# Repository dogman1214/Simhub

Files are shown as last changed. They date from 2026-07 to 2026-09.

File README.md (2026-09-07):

# Simhub
A custom-designed macropad design for my sim-racing use, and for general purpose as well.
This isn't physical at the moment, but rather a design you use to build your own macropad!

# Features:
* 3D - printed custom case
* 3 x 4 switch arrangement
* EC11 rotary encoder, with a switch built in
* USB-C connectivity
# CAD Model:

Everything is secured in place with 4 M3 screws and bolts, with the bolts serving a dual purpose as the base legs. The case is to be 3d-printed, along with the knob for the rotary encoder.

CAD
The render was made in Blender
The model was made in FreeCAD.

# PCB
This is the PCB, it was designed in KiCad.

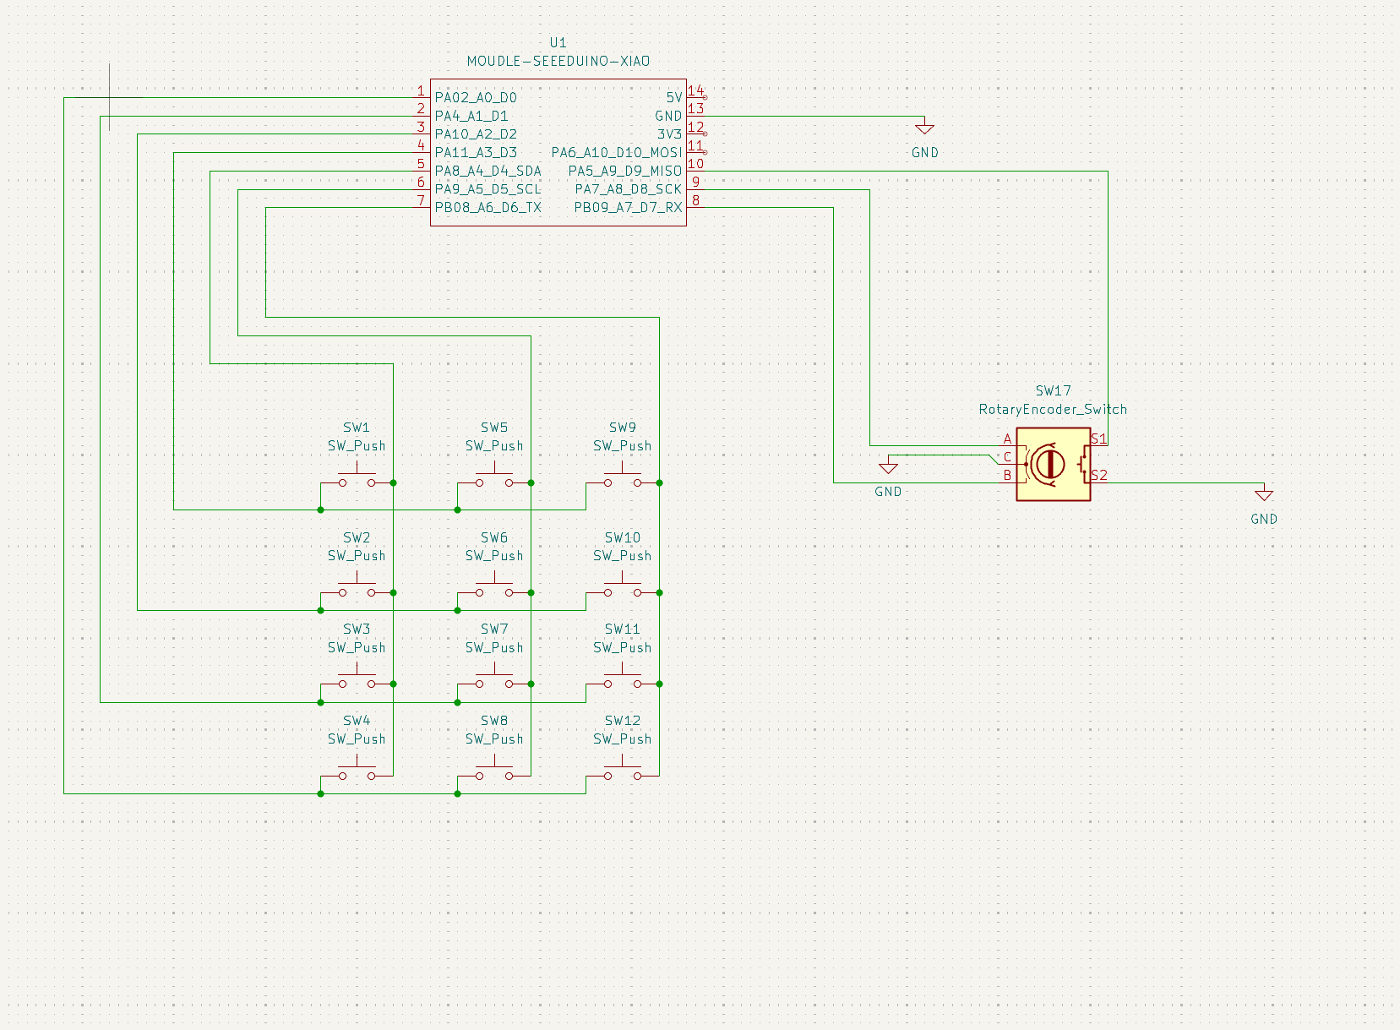
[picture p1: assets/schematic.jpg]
Schematic
Schematic 

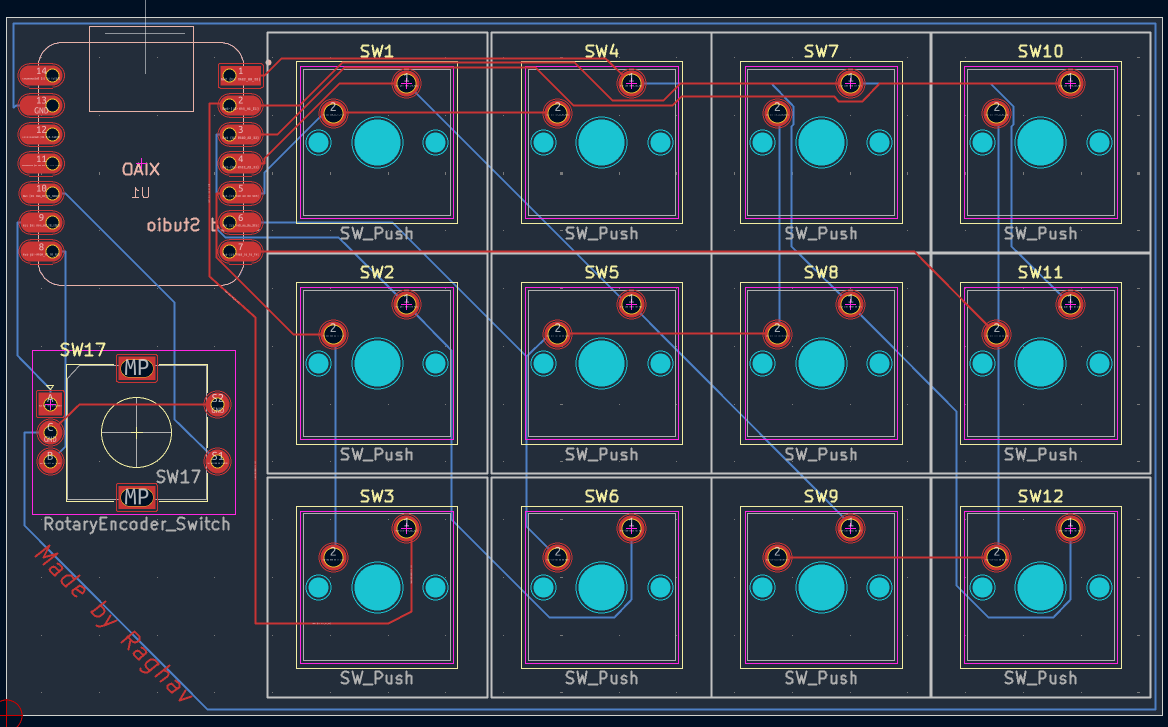
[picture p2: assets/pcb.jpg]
PCB
PCB 

# Firmware
This hackpad uses QMK firmware for everything.
Since it was designed with video-game assistance in mind, you have to map all the keys in-game to use them.

*This keyboard has two modes.*

To swap between custom in-game keyboard usage and a normal numpad style keyboard, click down on the rotary encoder.

#Be aware: This Bill of Materials is what is expected to be bought & used. I haven't built the macropad yet.

### BOM:
This is eveyrthing you need to make this macropad:
* 12x Cherry MX Switches
* 12x DSA Keycaps
* 4x M3x16mm nuts and bolts
* 1x EC11 Rotary Encoder
* 1x XIAO RP2040
* 1x Case (3 printed parts)

# Bill of Materials - what you'll realistically buy

| Item Number | Description | Quantity | Unit Price (USD) | Extended Price (USD) | Vendor | Link |
|---|---|---|---|---|---|---|
| 4809-EC11E15204A3-ND | EC11E15204A3 Alps Alpine ENCODER INCREM QUAD VERT PC PIN | 1 | 4.41 | 4.41 | Digi-Key | https://www.digikey.com/en/products/detail/alps-alpine/EC11E15204A3/21721644 |
| 1597-102010428-ND | 102010428 Seeed Technology Co., Ltd XIAO RP2040 | 1 | 4.88 | 4.88 | Digi-Key | https://www.digikey.com/en/products/detail/seeed-technology-co-ltd/102010428/14672129 |
| CHERRY MX2A RGB Brown Kit| 36 mechanical keyboard switches (tactile, no click) | 1 | 19.99 | 19.99 | Amazon | https://www.amazon.com/dp/B0FYR9Z777 |
| Fgruh 750PCS M3 Screws | M3 hex socket bolts/nuts/washers set | 1 | 9.99 | 9.99 | Amazon | https://www.amazon.com/dp/B0FGV5FCBN |
| NeWear Relegendable Caps | DSA-style customizable transparent keycaps (12 pack) | 1 | 12.50 | 12.50 | Amazon | https://www.amazon.com/dp/B0DH91XV4T |
| Simhubb-PCBfiles_Y2 | PCB prototype Y2-13145810A, Green, 1.6mm, HASL (with lead) | 5 | 0.40 | 2.00 | JLCPCB | (Generated from your Gerber ZIP; no product link) |
| Body.stl | 3D print PETG FDM, Standard finish, Translucent | 1 | 5.40 | 5.40 | Hudson Creative Group | (Custom print; no link) |
| Cover.stl | 3D print PETG FDM, Standard finish, Translucent | 1 | 5.40 | 5.40 | Hudson Creative Group | (Custom print; no link) |
| Knob.stl | 3D print PETG FDM, Standard finish, Translucent | 1 | 5.40 | 5.40 | Hudson Creative Group | (Custom print; no link) |
 |

I hope you like this project/macropad!

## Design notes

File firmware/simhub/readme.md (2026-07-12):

# Simhub
A custom 12-key handwired macropad with a rotary encoder powered by a Seeed XIAO RP2040
* Keyboard Maintainer: Raghav Sharma
* Hardware Supported: Seeed XIAO RP2040, MX style switches, EC11 rotary encoder, custom pcb.
* Hardware Availability: https://hackpad.hackclub.com/

Make example for this keyboard, after setting up the build environment:
```
make Simhub:default
```

Flashing example for this keyboard:
```
make Simhub:default:flash
```

See the [build environment setup](https://docs.qmk.fm/#/getting_started_build_tools) and the [make instructions](https://docs.qmk.fm/#/getting_started_make_guide) for more information.

# Bootloader
Enter the bootloader in 3 ways:
* Bootmagic reset: Hold down the top left key (the key at (0,0) and plug in the keyboard.
* Physical reset button: press the RESET button on the XIAO board while holding the BOOT button.
* Keycode in layout: Press the key mapped to QK_BOOT if it is available.

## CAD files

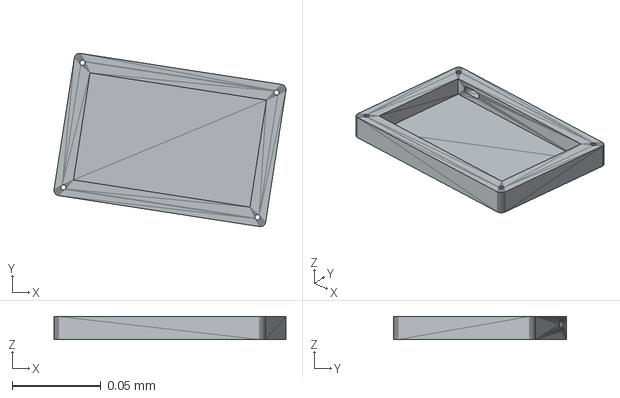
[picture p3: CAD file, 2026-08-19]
production/Body.step
0.13 x 0.0974 x 0.013 mm

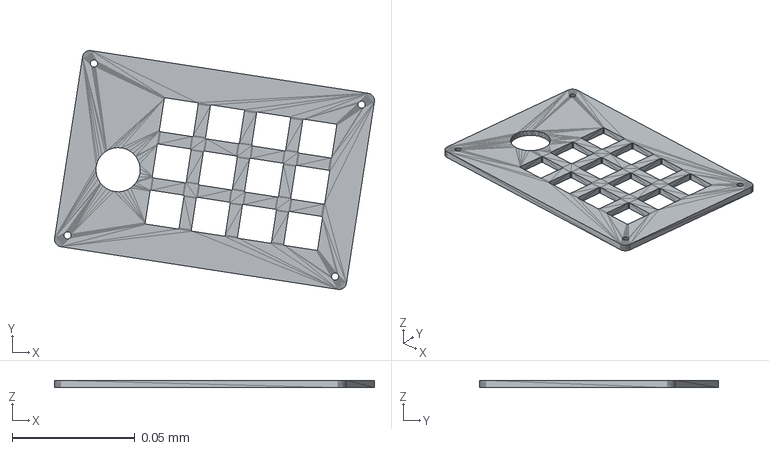
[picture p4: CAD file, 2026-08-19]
production/Cover.step
0.13 x 0.0974 x 0.003 mm

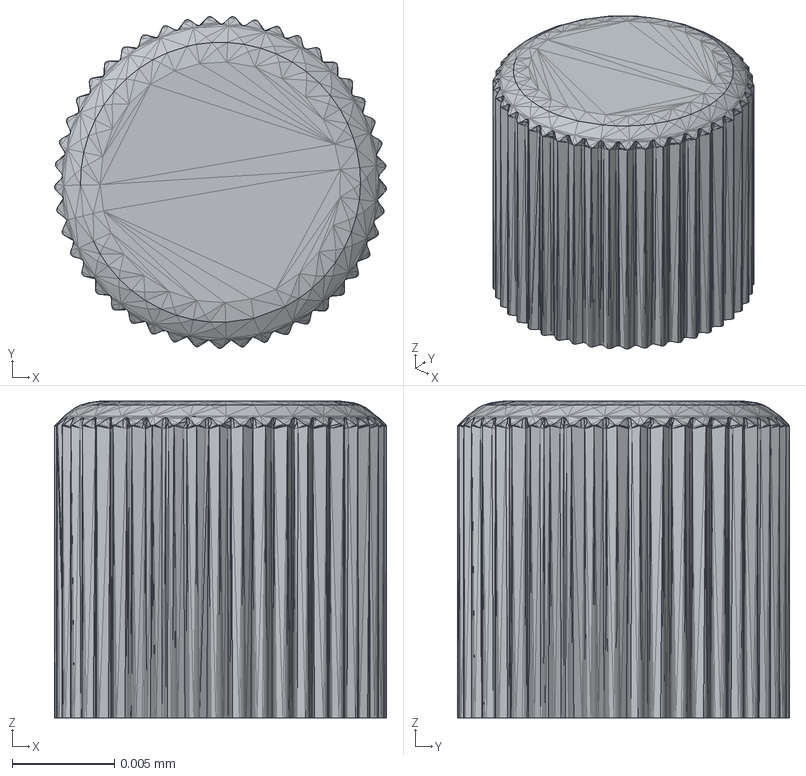
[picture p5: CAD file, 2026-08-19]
production/Knob.step
0.0163 x 0.0162 x 0.0155 mm

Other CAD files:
production/Body.stl
production/Cover.stl
production/Knob.stl

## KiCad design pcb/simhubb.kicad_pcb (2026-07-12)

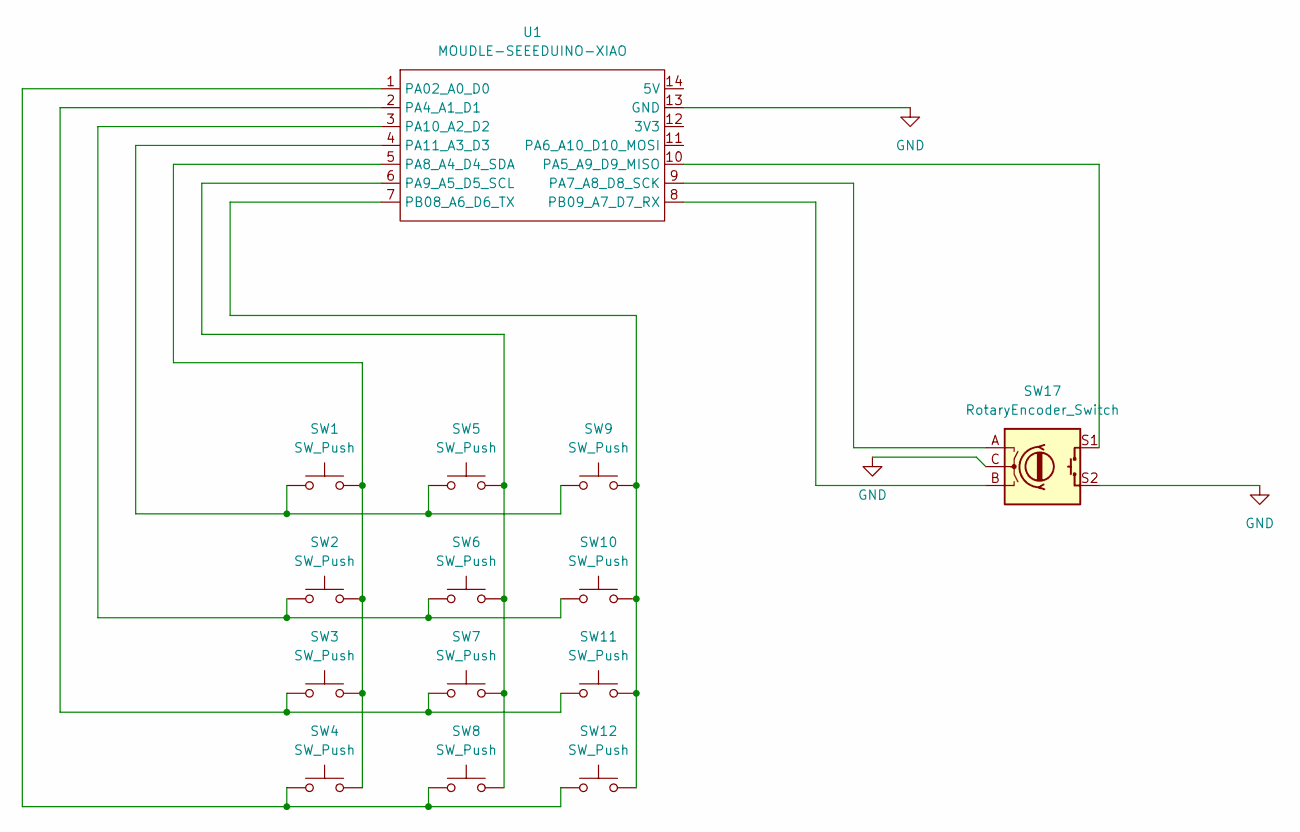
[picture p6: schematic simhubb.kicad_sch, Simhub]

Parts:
SW1, SW2, SW3, SW4, SW5, SW6, SW7, SW8, SW9, SW10, SW11, SW12: SW_Push; SW_Cherry_MX_1.00u_PCB
SW17: RotaryEncoder_Switch; RotaryEncoder_Alps_EC11E-Switch_Vertical_H20mm
U1: MOUDLE-SEEEDUINO-XIAO; XIAO-Generic-Hybrid-14P-2.54-21X17.8MM

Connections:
GND: SW17.C, SW17.S2, U1.13 (GND)
unnamed: SW4.1, SW8.1, SW12.1, U1.1 (PA02_A0_D0)
unnamed: SW3.1, SW7.1, SW11.1, U1.2 (PA4_A1_D1)
unnamed: SW17.S1, U1.10 (PA5_A9_D9_MISO)
unnamed: SW17.A, U1.9 (PA7_A8_D8_SCK)
unnamed: SW1.2, SW2.2, SW3.2, SW4.2, U1.5 (PA8_A4_D4_SDA)
unnamed: SW5.2, SW6.2, SW7.2, SW8.2, U1.6 (PA9_A5_D5_SCL)
unnamed: SW2.1, SW6.1, SW10.1, U1.3 (PA10_A2_D2)
unnamed: SW1.1, SW5.1, SW9.1, U1.4 (PA11_A3_D3)
unnamed: SW9.2, SW10.2, SW11.2, SW12.2, U1.7 (PB08_A6_D6_TX)
unnamed: SW17.B, U1.8 (PB09_A7_D7_RX)

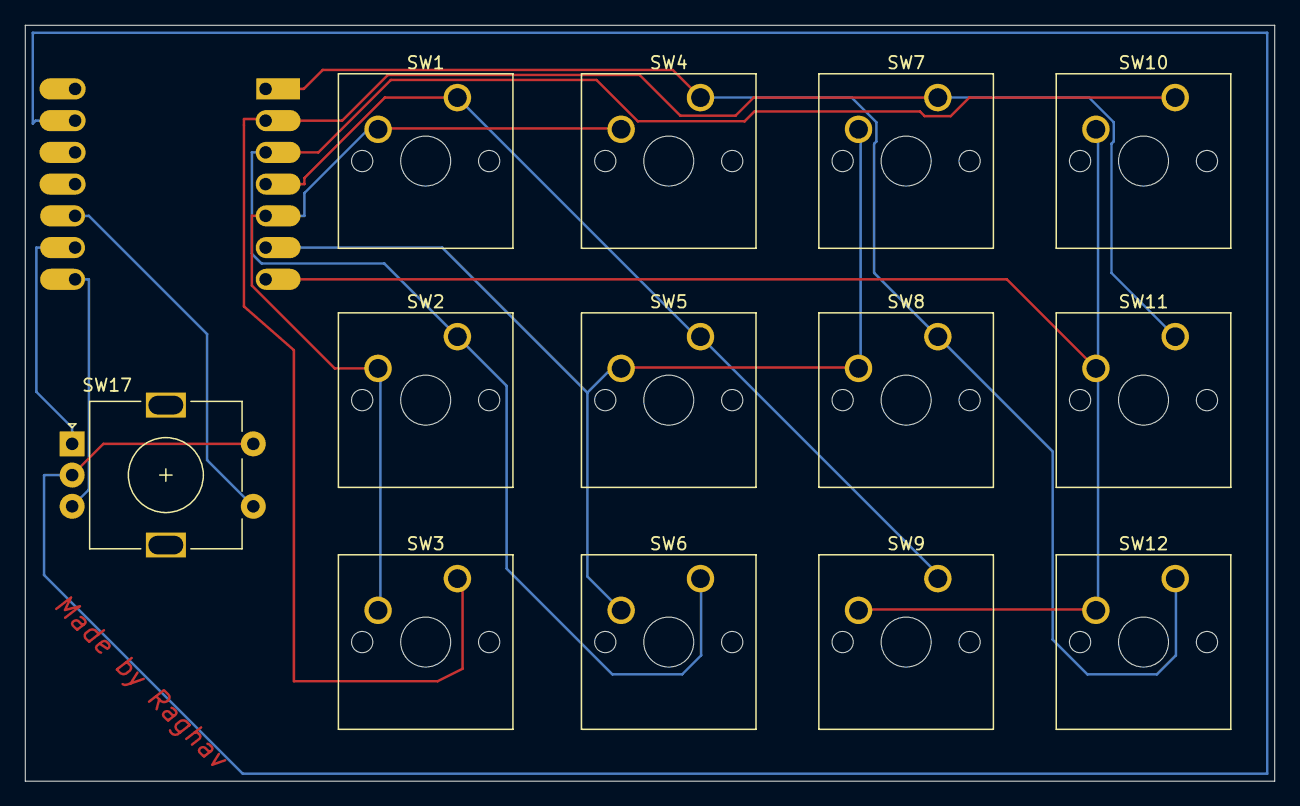
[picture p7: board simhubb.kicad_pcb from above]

Board: 2 copper layers, 100.0 x 60.5 mm, 14 parts (1 on the bottom side), 11 nets.

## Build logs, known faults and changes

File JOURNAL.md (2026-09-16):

---
title: "Simhub"
author: "Raghav"
description: "A hackpad mission, where I create a keyboard to adress all of my sim-racing needs. This macropad stands out from other ones because clicking down on the rotary encoder toggles it from custom macro shortcuts to a classic numpad. This is my first time using freecad and KiCAD, so appreciate your feedback.
"
created_at: "2026-03-20"
---

# 6/15/2026: setting things up
I don’t really know how kicad works, but that’s fine. I’ll learn.
The struggle right now, is importing everything. I belive I imported the libraries required, but I can’t find the symbols, which is wierd. Cheers!


**Total time spent: 0.25 hours**

# 6/16/2026: kicad stuff
Finished wiring the schematics.
I want to use 12 keys so that in the sim-racing game, I can set views, change traction control, brake balance, and all of the intricates.
I am also including one rotary encoder for things like volume control, so I can turn down the volume when my parents come by :)

**Total time spent: 0.9 hours**

# 6/17/2026: started pcb
Completed all the routing of the PCB
I realized that routing is a very sketchy task, especially for someone as inexperienced in this field as me. Fortunately, I found a plugin that does the routing for you!
It is called “Autorouting”
Please check it out, its really a life-saver.
Now onto the CAD portion of this project.


**Total time spent: 0.5 hours**

# 6/18/2026: fusion GENIUNELY TRASH
Trying to fix FUSION. I have ZERO IDEA why fusion isn’t working, just a blank screen. Tried all fixes on the web, but to no avail. Anyone here please help


**Total time spent: 2.1 hours**

# 6/19/2026: Working via freecad
Fusion Failed…
Fusion CAD software is genuinely terrible. Doesn’t work on my RTX 4080 even after multiple reinstalls. So I switched to FreeCAD. It is pretty different, but I am getting the hang of it.
I have completed a lot of the CAD work for this project, so we are getting there, to the point where we are done I guess. Most of the case is done, mayb the cap part remaining.


**Total time spent: 2.6 hours**

# 6/20/2026: Freecad brainslop
djusting to FreeCAD is difficult after fusion doesn’t work anymore. After long coercion I am able to create a rough sketch that I can develop further.
fingers crossed, I can hopefully finish this project nice and tidy! 'm working on the cap, i set up the pcb and stuff and its all going along nicely.


**Total time spent: 1.2 hours**

# 7/10/2026: Still working on the freecad stuff. 
The case is basically done, but i wanna align all the keycaps and rotary encoders so taht i get a good visual representation of wth i even made.


**Total time spent: 0.91 hours**

# 7/15/2026: Blendering Rendering
I imported my model into blender for rendering a nice photo so that people have a good idea what I’m making. Probably will re-render with some adjustments, along with turning on denoise and then adding some artificial ISO noise. But hopefully the first ship is coming by soon! I placed very aesthetic objects, set up a custom camera, and tried to frame the image to look as yummy as possible.


**Total time spent: 2.8 hours**

# 7/16/2026: Blending my stuff even more
Trying to see how to improve the example image. But I’m also building the github, along with drafting the silkscreen
I’m trying to follow the guide, but improve on eveyrthing, like a better and more extensive readme and whatnot. As per the blender render, I’m taking feedback from my family to see what is too much and what to improve.
Idk what to improve, but somethings off...


**Total time spent: 8.5 hours**

# 7/20/2026: Wrapping up stuff, maybe.
Everthing is practically done! The github is set up, the demo is linked. I just have to recieve the files.  Really just proring over the fine details to see whetehr i missed sum


**Total time spent: 1.6 hours**

# 8/15/2026: finalizing stuff. Submitting after this
Just wrapping up github info.


**Total time spent: 1.1 hours**

# 9/15/2026: Transition to Forge
Hi guys, unfortunately, since Stardance is ending in 15 days, i wanna transition all my projects to forge. IK its wierd, but i just wanna make sure my things aren't rushed. I already got the funding and parts shipped (haven't arrived yet), but I wanna publish onto Forge. I don't think this is double dipping, since I abandoned stardance, and want to go to force for the final "forge" or ship or whatever. I wont ship on stardance.
This is what my ship for funding was from stardance:
"A custom macropad, where I design a small keyboard to address all of my sim-racing needs. This is mainly a design project for now. I won’t be able to recieve the parts I got funding for (so I didn’t use the funding) before September 30th, so I’m submitting this design. This macropad stands out from other ones because clicking down on the rotary encoder toggles it from custom macro shortcuts to a classic numpad. This is my first time using freecad and KiCAD, so appreciate your feedback.
This macropad consists of 12 switches and one rotary encoder with a switch feature. It is designed with a 3d-printable body, so feel free to use whatever colors you want! Same with the rotary encoder knob.
Thanks a lot guys, this mission really taught me well about CAD and PCB design. It paved the way to my current project, which you can check in my profile."


**Total time spent: 0.15 hours**

# 9/16/2026: Alr everything set up and ready to go!


**Total time spent: 0.5 hours**

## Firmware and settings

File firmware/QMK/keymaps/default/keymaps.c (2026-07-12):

#include QMK_KEYBOARD_H

enum custom_layers {
    _DESKTOP = 0,
    _GAMING = 1
};

const uint16_t PROGMEM keymaps[][MATRIX_ROWS][MATRIX_COLS] = {
    [_DESKTOP] = LAYOUT(
        KC_7,    KC_8,    KC_9,
        KC_4,    KC_5,    KC_6,
        KC_1,    KC_2,    KC_3,
        KC_MUTE, KC_0,    KC_ENT
    ),
    [_GAMING] = LAYOUT(
        KC_F13,  KC_F14,  KC_F15,
        KC_F16,  KC_F17,  KC_F18,
        KC_F19,  KC_F20,  KC_F21,
        KC_F22,  KC_F23,  KC_F24
    )
};

#if defined(ENCODER_MAP_ENABLE)
const uint16_t PROGMEM encoder_map[][NUM_ENCODERS][NUM_DIRECTIONS] = {
    [_DESKTOP] = { ENCODER_CCW_CW(KC_VOLD, KC_VOLU) },
    [_GAMING]  = { ENCODER_CCW_CW(KC_PGDN, KC_PGUP) }
};
#endif

void keyboard_post_init_user(void) {
    setPinInputHigh(GP4);
}

void matrix_scan_user(void) {
    static bool last_button_state = false;
    bool current_button_state = !readPin(GP4);

    if (current_button_state != last_button_state) {
        if (current_button_state) {
            layer_invert(_GAMING);
        }
        last_button_state = current_button_state;
    }
}

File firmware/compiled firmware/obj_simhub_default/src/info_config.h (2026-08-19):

// Copyright 2026 QMK
// SPDX-License-Identifier: GPL-2.0-or-later

/*******************************************************************************
  88888888888 888      d8b                .d888 d8b 888               d8b
      888     888      Y8P               d88P"  Y8P 888               Y8P
      888     888                        888        888
      888     88888b.  888 .d8888b       888888 888 888  .d88b.       888 .d8888b
      888     888 "88b 888 88K           888    888 888 d8P  Y8b      888 88K
      888     888  888 888 "Y8888b.      888    888 888 88888888      888 "Y8888b.
      888     888  888 888      X88      888    888 888 Y8b.          888      X88
      888     888  888 888  88888P'      888    888 888  "Y8888       888  88888P'
                                                        888                 888
                                                        888                 888
                                                        888                 888
     .d88b.   .d88b.  88888b.   .d88b.  888d888 8888b.  888888 .d88b.   .d88888
    d88P"88b d8P  Y8b 888 "88b d8P  Y8b 888P"      "88b 888   d8P  Y8b d88" 888
    888  888 88888888 888  888 88888888 888    .d888888 888   88888888 888  888
    Y88b 888 Y8b.     888  888 Y8b.     888    888  888 Y88b. Y8b.     Y88b 888
     "Y88888  "Y8888  888  888  "Y8888  888    "Y888888  "Y888 "Y8888   "Y88888
         888
    Y8b d88P
     "Y88P"
*******************************************************************************/

#pragma once

#ifndef DIODE_DIRECTION
#    define DIODE_DIRECTION COL2ROW
#endif // DIODE_DIRECTION

#ifndef DEVICE_VER
#    define DEVICE_VER 0x0001
#endif // DEVICE_VER

#ifndef MANUFACTURER
#    define MANUFACTURER "Custom"
#endif // MANUFACTURER

#ifndef PRODUCT
#    define PRODUCT "Simhub"
#endif // PRODUCT

#ifndef PRODUCT_ID
#    define PRODUCT_ID 0x0000
#endif // PRODUCT_ID

#ifndef VENDOR_ID
#    define VENDOR_ID 0xFEED
#endif // VENDOR_ID

#ifndef MATRIX_COLS
#    define MATRIX_COLS 3
#endif // MATRIX_COLS

#ifndef MATRIX_ROWS
#    define MATRIX_ROWS 4
#endif // MATRIX_ROWS

#ifndef MATRIX_COL_PINS
#    define MATRIX_COL_PINS { GP6, GP7, GP0 }
#endif // MATRIX_COL_PINS

#ifndef MATRIX_ROW_PINS
#    define MATRIX_ROW_PINS { GP26, GP27, GP28, GP29 }
#endif // MATRIX_ROW_PINS

#ifndef ENCODER_A_PINS
#    define ENCODER_A_PINS { GP2 }
#endif // ENCODER_A_PINS

#ifndef ENCODER_B_PINS
#    define ENCODER_B_PINS { GP1 }
#endif // ENCODER_B_PINS

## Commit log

2026-07-12 Update README with features and design details
    Added detailed features, CAD model information, and PCB design notes.
2026-07-12 Add keymap and encoder support for QMK firmware
2026-07-12 Add default keymap and encoder support
2026-07-12 Rename Screenshot 2026-07-11 192156.png to schematic
2026-07-12 Rename Screenshot 2026-07-11 201307.png to pcb.jpg
2026-07-12 Added CAD file, removed placeholder
2026-07-12 Updated PCB files
    added all the files relating to the PCB, removed placeholder file
    [simhubb.kicad_pcb, simhubb.kicad_sch]
2026-07-12 Added STL files
    for 3d printing n all
    [Body.stl, Cover.stl, Knob.stl]
2026-07-12 Revise README with updated images and firmware info
    Updated images and descriptions for CAD, PCB, and firmware sections.
2026-07-12 Label schematic and PCB images in README
    Added labels to schematic and PCB images in README.
2026-07-12 Implement multiple layers in keymap configuration
    Added support for multiple layers in keymap configuration, including a gaming layer with different key assignments and encoder mappings.
    Click down on the encoder to swap modes.
    [keymaps.c]
2026-07-12 Update README with keyboard mode instructions
    Added information about keyboard modes and rotary encoder usage.
2026-07-12 cad.jpg udpated
2026-07-12 Correct number of screws in README
    Updated the number of screws from 3 to 4 in the assembly description.
2026-07-23 Add BOM.csv with item details and pricing
    [BOM.csv]
2026-07-23 Add Bill of Materials section to README
    Added a detailed Bill of Materials (BOM) section with item descriptions, quantities, prices, and vendors for the macropad project.
2026-07-23 Add 3D print files to BOM.csv
    Added 3D print files for body, cover, and knob in BOM.
    [BOM.csv]
2026-07-23 Update README with BOM note
    Added a note about the Bill of Materials and its status.
2026-07-23 Added gerbers.zip
2026-08-07 Update Bill of Materials with vendor links
    Added links to vendors for each item in the Bill of Materials.
2026-08-07 Add 'Link' column with product URLs to BOM.csv
    Added a 'Link' column to BOM.csv with URLs for each item.
    [BOM.csv]
2026-08-07 Format item descriptions with quotes in BOM.csv
    Updated item descriptions in BOM.csv to include quotes.
    [BOM.csv]
2026-08-07 Fix description formatting for XIAO RP2040
    Updated the description of the XIAO RP2040 item to include quotes.
    [BOM.csv]
2026-08-19 Added .step files
    [Body.step, Cover.step, Knob.step]
